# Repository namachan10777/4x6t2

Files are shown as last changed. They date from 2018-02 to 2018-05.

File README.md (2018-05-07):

# 4x6t2


4x6t2

A splited keyboard.
# License
MIT License 
Copyright (c) 2018 Nakano Masaki
## Exception
 * ./pcb/lib/4x6t2.pretty/MX_ALPS_KH_u1.00.kicad_mod
 * ./pcb/lib/4x6t2.pretty/D_SOD-123.kicad_mod
 * ./pcb/lib/4x6t2.pretty/LED_D3.0mm.kicad_mod
 * ./pcb/lib/4x6t2.pretty/R_Axial.kicad_mod
 * ./pcb/lib/4x6t2.pretty/SW_Tactile_SPST_Angled.kicad_mod
These footprint's original author is KiCAD.
These are distributed under CC-BY-SA 4.0.

# Third party
## helix
### point of use
 * Key footprint (./pcb/lib/4x6t2.pretty/MX_ALPS_KH_u1.00.kicad_mod) (modified)
 * Audio Jack footprint (./pcb/lib/4x6t2.pretty/MJ-4PP-9_rev2.kicad_mod)
### LICENSE
>Copyright (c) 2018 MakotoKurauchi
>
>Permission is hereby granted, free of charge, to any person obtaining a copy
>of this software and associated documentation files (the "Software"), to deal
>in the Software without restriction, including without limitation the rights
>to use, copy, modify, merge, publish, distribute, sublicense, and/or sell
>copies of the Software, and to permit persons to whom the Software is
>furnished to do so, subject to the following conditions:
>
>The above copyright notice and this permission notice shall be included in all
>copies or substantial portions of the Software.
>
>THE SOFTWARE IS PROVIDED "AS IS", WITHOUT WARRANTY OF ANY KIND, EXPRESS OR
>IMPLIED, INCLUDING BUT NOT LIMITED TO THE WARRANTIES OF MERCHANTABILITY,
>FITNESS FOR A PARTICULAR PURPOSE AND NONINFRINGEMENT. IN NO EVENT SHALL THE
>AUTHORS OR COPYRIGHT HOLDERS BE LIABLE FOR ANY CLAIM, DAMAGES OR OTHER
>LIABILITY, WHETHER IN AN ACTION OF CONTRACT, TORT OR OTHERWISE, ARISING FROM,
>OUT OF OR IN CONNECTION WITH THE SOFTWARE OR THE USE OR OTHER DEALINGS IN THE
>SOFTWARE.

## KiCAD Library
### LICENSE
CC-BY-SA 4.0
Copyright (c) KiCAD

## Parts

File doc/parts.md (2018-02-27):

# Basic
## Electrical parts
| Name | Qty |
|---|-----|
| SBD | 52  |
| Key Switch | 52  |
| 10 kΩ Resister | 6 |
| RJ45 Socket | 2 |
| 24p IC socket | 2 |
| Arduino Pro Micro | 2 |
| SPST snap in angled tactile switch | 2 |
## 3d parts
| Name | Qty |
|---|-----|
| spacer.stl | 4 |
| large_spacer.stl | 4 |
| vmount.stl | 2 |
| low_spacer.stl | 4 |
## PCB
| Name | Qty |
|---|---|
| left | 1 |
| right | 1 |
| breakout (Optional) | 25 x 3 |
## Mechanical Parts
| Name | Qty |
|---|-----|
| M3 20 screw | 6 |
| M3 nut | 6 |
| M6 screw (Optional) | 4 |
| M6 nut (Optional) | 8 |
# LED
## Electrical parts
| Name | Qty |
|---|-----|
| LED | 6 |
| Resister for LED | 6 |
# Sidebutton
## Electrical parts
| Name | Qty |
|---|-----|
| SPST tactile switch  | 1 |
| JT8P-3.2T-B10K-1-16Y | 1 |
## 3d parts
| Name | Qty |
|---|-----|
| joystick_cover.stl | 1 |
## PCB
| Name | Qty |
|---|-----|
| sidebutton | 1 |
## Mechanical parts
| Name | Qty |
|---|-----|
| M3 20 screw | 2 |
| M3 nut | 2 |
# Others
 * solder
 * wire

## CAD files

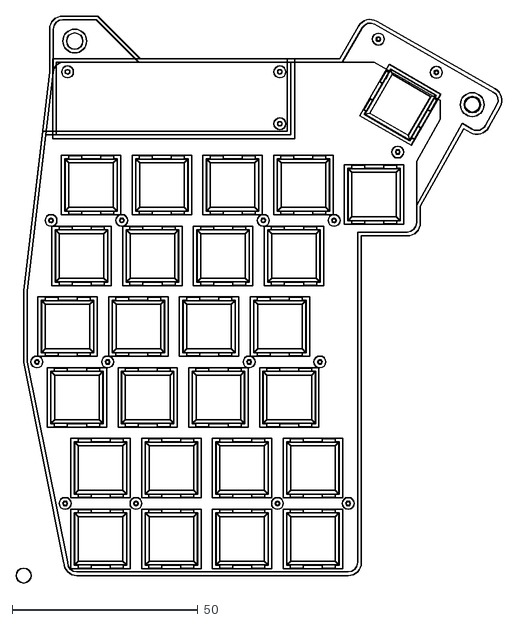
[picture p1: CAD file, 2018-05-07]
plate/plate.dxf
131.2 x 152.7

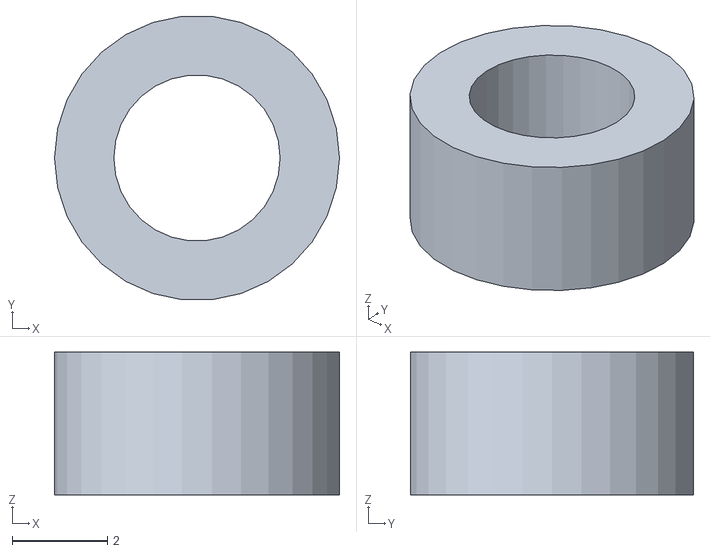
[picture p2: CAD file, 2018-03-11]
things/spacer.stl
6.00 x 5.97 x 3.00

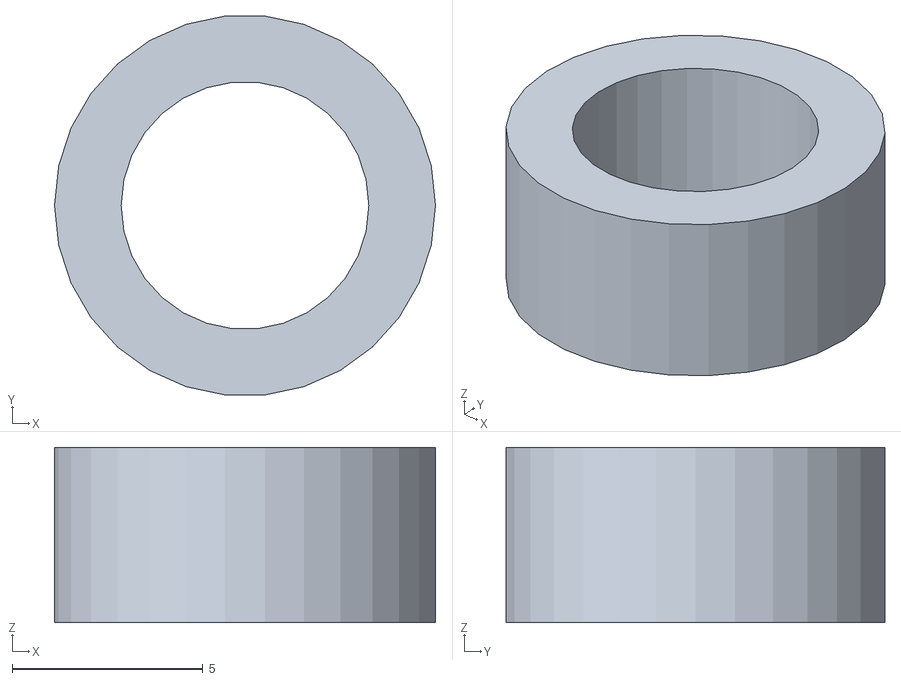
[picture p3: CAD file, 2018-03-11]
things/large_spacer.stl
10.0 x 9.95 x 4.60

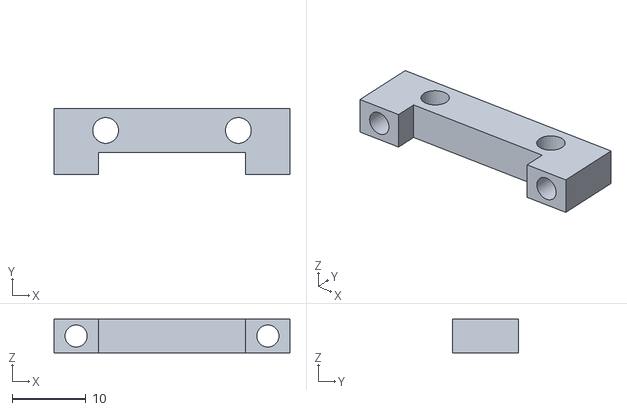
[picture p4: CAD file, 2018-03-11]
things/vmount.stl
32.0 x 9.00 x 4.60

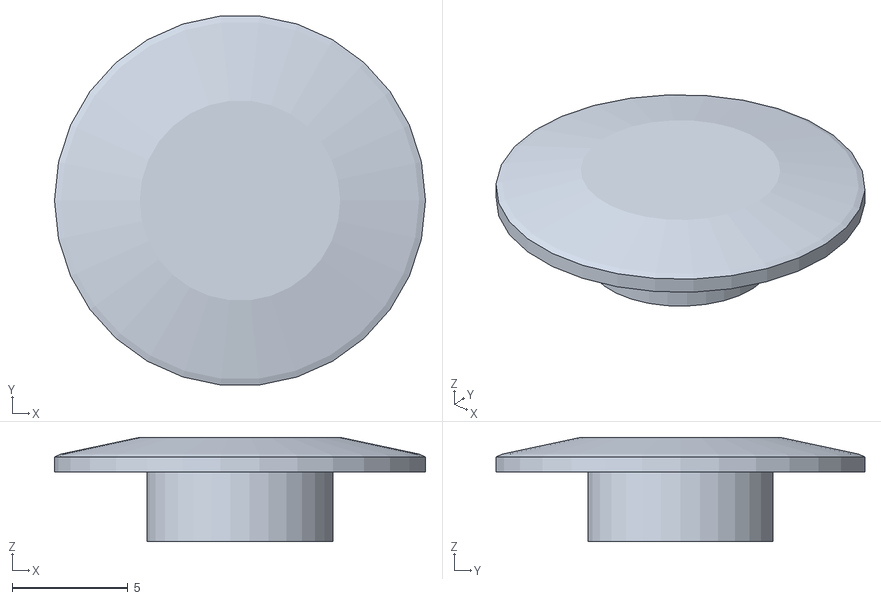
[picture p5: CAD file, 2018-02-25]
things/joystick_cover.stl
16.0 x 15.9 x 4.50

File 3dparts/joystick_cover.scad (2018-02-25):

difference() {
    intersection () {
        union() {
            cylinder(r=4, h=3, $fs=0.1);
            translate([0,0,3]) {
                cylinder(r=8, h=1.5, $fs=0.1);
            }
        }
        translate([0,0,-20]) {
            sphere(25);
        }
    }
    translate([-3.5/2,-4.5/2,0]) {
        cube([3.5,4.5,3]);
    }
}

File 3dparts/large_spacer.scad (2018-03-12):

difference(){
	height = 2.2+3+0.5-1.5;
    cylinder(r=5, h=height, center=true, $fs=0.1);
    cylinder(r=3.25, h=height, center=true, $fs=0.1);
}

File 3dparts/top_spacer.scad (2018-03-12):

difference() {
	height=1;
	hole_r=1.75;
	$fs=0.1;
	cylinder(h=height, r=3);
	cylinder(h=height, r=hole_r);
}

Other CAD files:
3dparts/under_spacer.scad
3dparts/vmount.scad

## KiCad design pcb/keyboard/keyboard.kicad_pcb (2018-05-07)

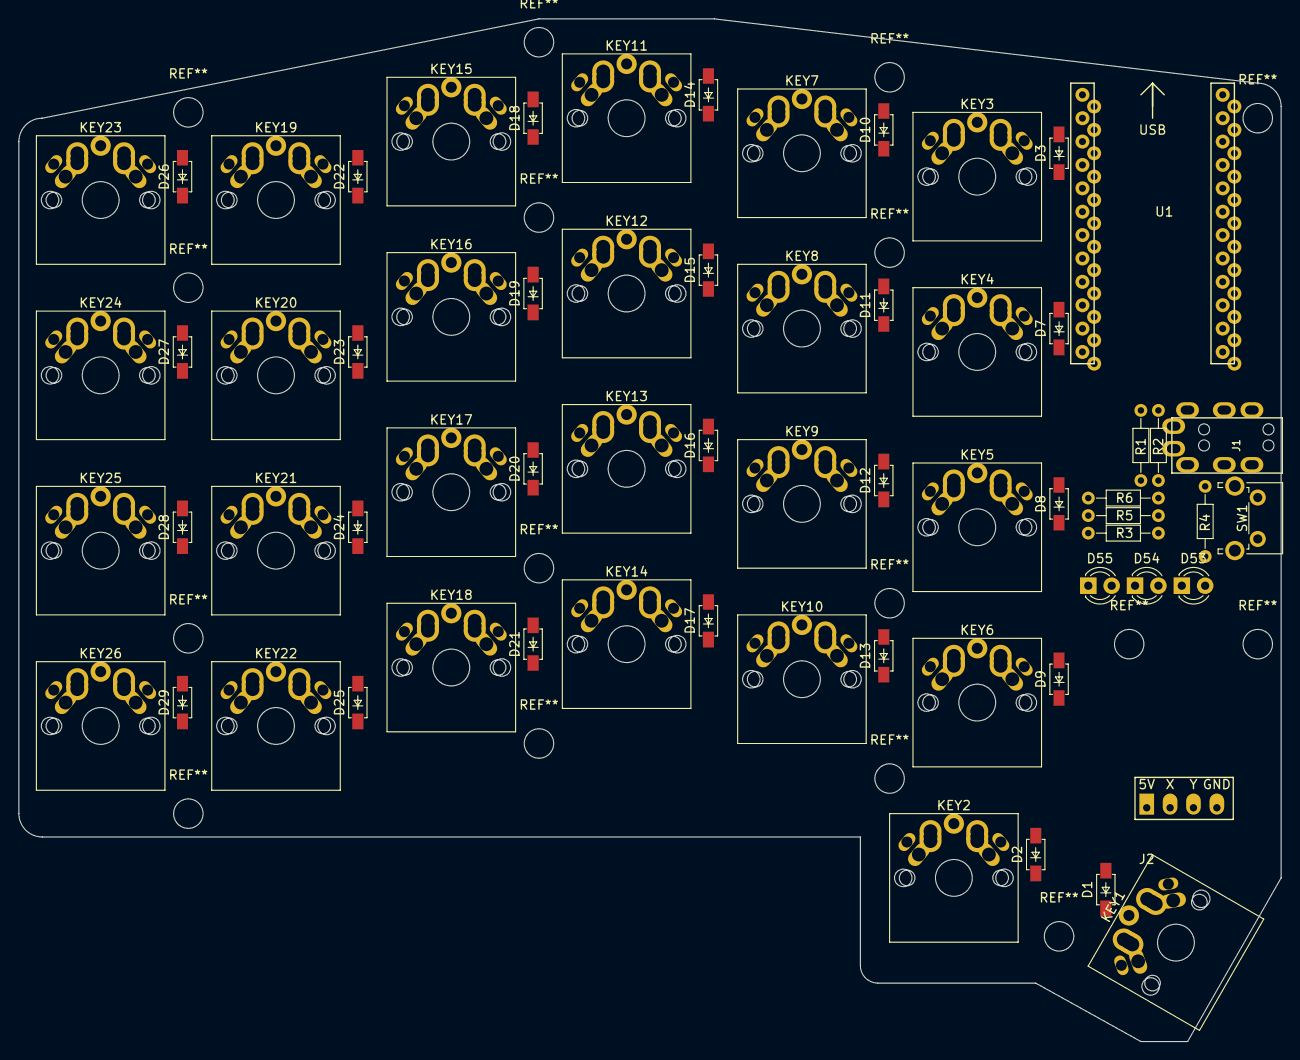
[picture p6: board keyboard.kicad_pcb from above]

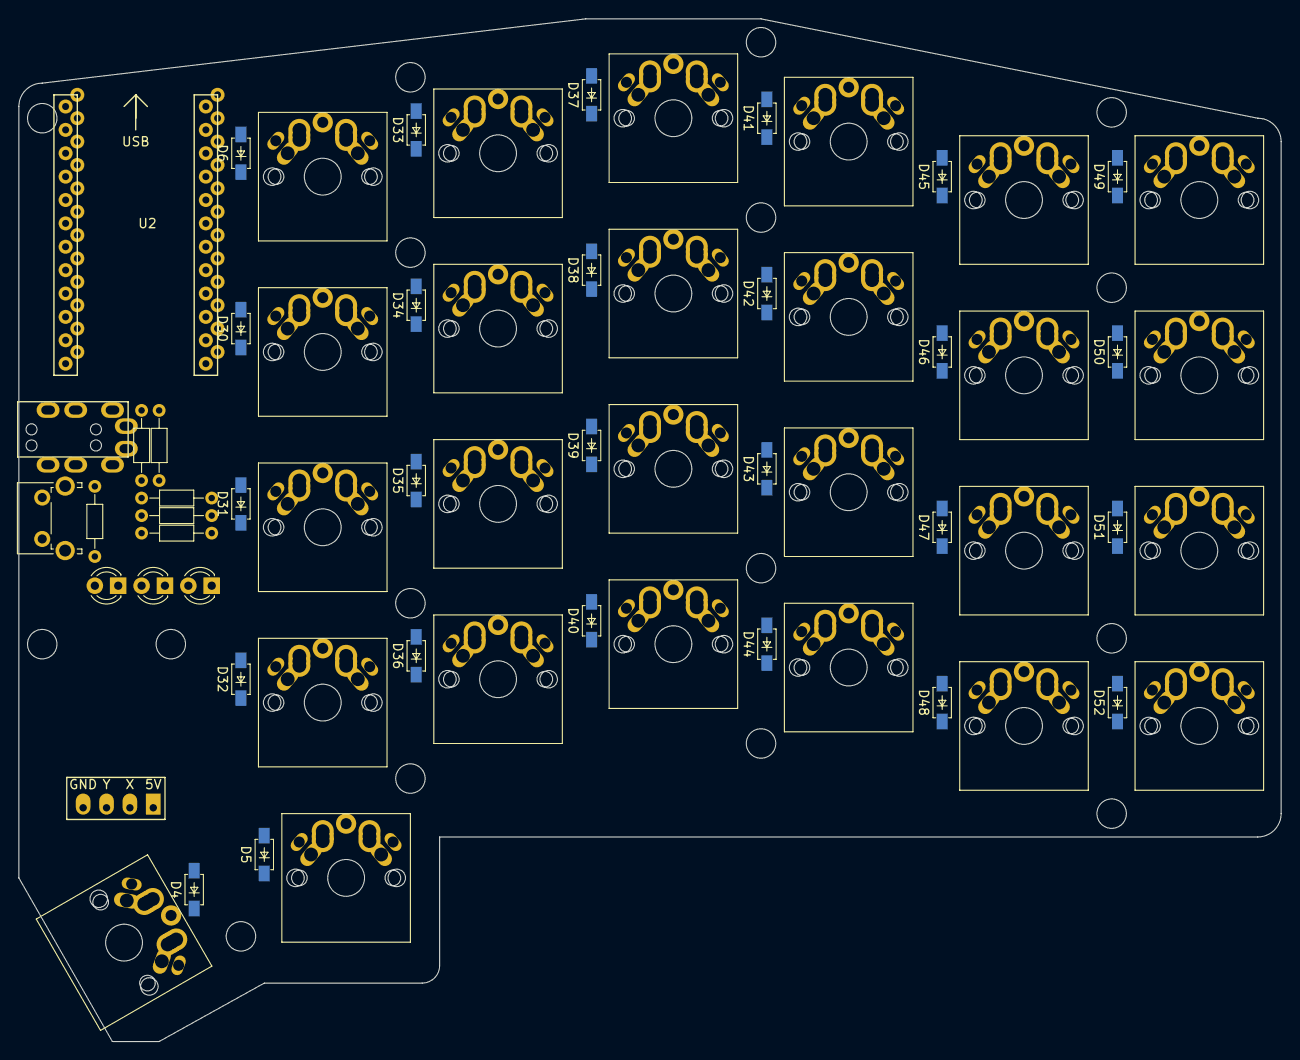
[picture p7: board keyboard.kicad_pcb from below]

Board: 2 copper layers, 137.2 x 111.1 mm, 92 parts (27 on the bottom side), 50 nets, no tracks yet.

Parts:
D1, D2, D3, D4, D5, D6, D7, D8, D9, D10, D11, D12, D13, D14, D15, D16, D17, D18, D19, D20, D21, D22, D23, D24, D25, D26, D27, D28, D29, D30, D31, D32, D33, D34, D35, D36, D37, D38, D39, D40, D41, D42, D43, D44, D45, D46, D47, D48, D49, D50, D51, D52: D; D_SOD-123
D53, D54, D55: LED; LED_D3.0mm
J1: Audio-Jack-4; MJ-4PP-9_rev2
J2: sidebutton; Wirepad_01x04
KEY1: KEY20; MX_ALPS_KH_u1.00
KEY2: KEY30; MX_ALPS_KH_u1.00
KEY3: KEY01; MX_ALPS_KH_u1.00
KEY4: KEY11; MX_ALPS_KH_u1.00
KEY5: KEY21; MX_ALPS_KH_u1.00
KEY6: KEY31; MX_ALPS_KH_u1.00
KEY7: KEY02; MX_ALPS_KH_u1.00
KEY8: KEY12; MX_ALPS_KH_u1.00
KEY9: KEY22; MX_ALPS_KH_u1.00
KEY10: KEY32; MX_ALPS_KH_u1.00
KEY11: KEY03; MX_ALPS_KH_u1.00
KEY12: KEY13; MX_ALPS_KH_u1.00
KEY13: KEY23; MX_ALPS_KH_u1.00
KEY14: KEY33; MX_ALPS_KH_u1.00
KEY15: KEY04; MX_ALPS_KH_u1.00
KEY16: KEY14; MX_ALPS_KH_u1.00
KEY17: KEY24; MX_ALPS_KH_u1.00
KEY18: KEY34; MX_ALPS_KH_u1.00
KEY19: KEY05; MX_ALPS_KH_u1.00
KEY20: KEY15; MX_ALPS_KH_u1.00
KEY21: KEY25; MX_ALPS_KH_u1.00
KEY22: KEY35; MX_ALPS_KH_u1.00
KEY23: KEY06; MX_ALPS_KH_u1.00
KEY24: KEY16; MX_ALPS_KH_u1.00
KEY25: KEY26; MX_ALPS_KH_u1.00
KEY26: KE36; MX_ALPS_KH_u1.00
R1, R2: 10kΩ; R_Axial
R3, R5, R6: 100Ω; R_Axial
R4: R; R_Axial
SW1: RESET_SW; SW_Tactile_SPST_Angled
U1, U2: Arduino_Pro_Micro

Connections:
+5V: J1.3, J2.1, R1.1, R2.1, R3.1, R4.1, R5.1, R6.1, U1.21, U2.21
/COL0: D1.2, D2.2, D4.2, D5.2, U1.17, U2.17
/COL1: D3.2, D6.2, D7.2, D8.2, D9.2, D30.2, D31.2, D32.2, U1.16, U2.16
/COL2: D10.2, D11.2, D12.2, D13.2, D33.2, D34.2, D35.2, D36.2, U1.15, U2.15
/COL3: D14.2, D15.2, D16.2, D17.2, D37.2, D38.2, D39.2, D40.2, U1.14, U2.14
/COL4: D18.2, D19.2, D20.2, D21.2, D41.2, D42.2, D43.2, D44.2, U1.13, U2.13
/COL5: D22.2, D23.2, D24.2, D25.2, D45.2, D46.2, D47.2, D48.2, U1.11, U2.11
/COL6: D26.2, D27.2, D28.2, D29.2, D49.2, D50.2, D51.2, D52.2, U1.12, U2.12
/LED1: D53.1, U1.20, U2.20
/LED2: D54.1, U1.19, U2.19
/LED3: D55.1, U1.18, U2.18
/ROW0: KEY3.1, KEY7.1, KEY11.1, KEY15.1, KEY19.1, KEY23.1, U1.1, U2.1
/ROW1: KEY4.1, KEY8.1, KEY12.1, KEY16.1, KEY20.1, KEY24.1, U1.2, U2.2
/ROW2: KEY1.1, KEY5.1, KEY9.1, KEY13.1, KEY17.1, KEY21.1, KEY25.1, U1.8, U2.8
/ROW4: KEY2.1, KEY6.1, KEY10.1, KEY14.1, KEY18.1, KEY22.1, KEY26.1, U1.10, U2.10
/RST: R4.2, SW1.1, U1.22, U2.22
/SCL: J1.1, R1.2, U1.6, U2.6
/SDA: J1.2, R2.2, U1.5, U2.5
/X: J2.2, U1.9, U2.9
/Y: J2.3, U1.7, U2.7
GND: J1.4, J2.4, SW1.2, U1.3, U1.4, U1.23, U2.3, U2.4, U2.23
unnamed: D1.1, D4.1, KEY1.2
unnamed: D2.1, D5.1, KEY2.2
unnamed: D3.1, D6.1, KEY3.2
unnamed: D10.1, D33.1, KEY7.2
unnamed: D11.1, D34.1, KEY8.2
unnamed: D12.1, D35.1, KEY9.2
unnamed: D13.1, D36.1, KEY10.2
unnamed: D14.1, D37.1, KEY11.2
unnamed: D15.1, D38.1, KEY12.2
unnamed: D16.1, D39.1, KEY13.2
unnamed: D17.1, D40.1, KEY14.2
unnamed: D18.1, D41.1, KEY15.2
unnamed: D19.1, D42.1, KEY16.2
unnamed: D20.1, D43.1, KEY17.2
unnamed: D21.1, D44.1, KEY18.2
unnamed: D22.1, D45.1, KEY19.2
unnamed: D23.1, D46.1, KEY20.2
unnamed: D24.1, D47.1, KEY21.2
unnamed: D25.1, D48.1, KEY22.2
unnamed: D26.1, D49.1, KEY23.2
unnamed: D27.1, D50.1, KEY24.2
unnamed: D28.1, D51.1, KEY25.2
unnamed: D29.1, D52.1, KEY26.2
unnamed: D7.1, D30.1, KEY4.2
unnamed: D8.1, D31.1, KEY5.2
unnamed: D9.1, D32.1, KEY6.2
unnamed: D53.2, R3.2
unnamed: D54.2, R5.2
unnamed: D55.2, R6.2

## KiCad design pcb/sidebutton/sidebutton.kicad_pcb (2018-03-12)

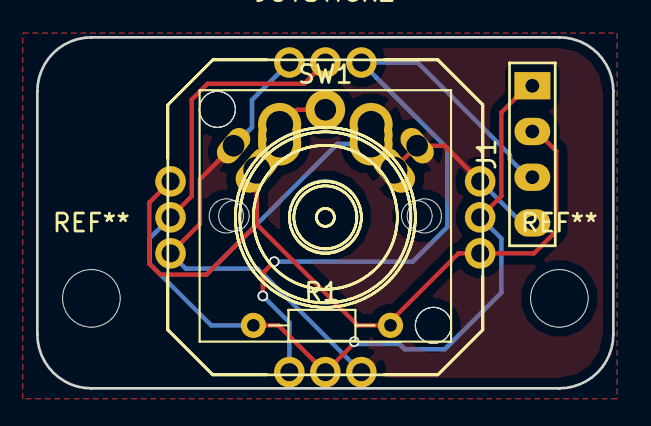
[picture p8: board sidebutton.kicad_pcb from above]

Board: 2 copper layers, 32.0 x 19.5 mm, 5 parts (0 on the bottom side), 4 nets.

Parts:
J1: Conn_01x04; Wirepad_01x04
JOYSTICK1, JOYSTICK2: JT8P-3.2T-B10K-1-16Y
R1: R; R_Axial_DIN0204_L3.6mm_D1.6mm_P7.62mm_Horizontal
SW1: SW_DIP_x01; MX_ALPS_KH_u1.00

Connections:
+5V: J1.1, JOYSTICK1.2, JOYSTICK1.5, JOYSTICK2.2, JOYSTICK2.5, R1.1
/out1: J1.2, JOYSTICK1.4, JOYSTICK2.4, R1.2, SW1.2
/out2: J1.3, JOYSTICK1.1, JOYSTICK2.1
GND: J1.4, JOYSTICK1.3, JOYSTICK1.6, JOYSTICK2.3, JOYSTICK2.6, SW1.1

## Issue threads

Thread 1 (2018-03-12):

KiCAdライブラリのライセンス

namachan10777, 2018-03-12:
CC-BY-SA 4.0かGPL v2.どちらにせよ違反なので修正

Closed 2018-03-14.

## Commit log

2018-02-18 add RJ45-8pin KiCADのRJ45はフットプリントと対応してない(なんで)ので
2018-02-18 lib: add Arduino Pro Micro
2018-02-19 left: add schematic
    [left.sch]
2018-02-19 add 30 degree rotated key footprint
2018-02-19 add joystic to schematic
    [left.sch]
2018-02-19 add left pcb arrangement
    [left.kicad_pcb]
2018-02-20 add joystick pcb
    [joystick.kicad_pcb, joystick.sch]
2018-02-20 improve pcb design
    [joystick.kicad_pcb, joystick.sch, left.kicad_pcb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]
2018-02-21 improve key arrangement
    [left.kicad_pcb, left.sch, sidebutton.kicad_pcb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]
2018-02-22 add plate artwork
    [plate.dxf]
2018-02-23 fix sidebutton めっちゃブリッジしそうで怖い
    [sidebutton.kicad_pcb, sidebutton.sch]
2018-02-23 small pcb キーの配線は空中配線で
    [left.kicad_pcb, left.sch]
2018-02-23 left: place all parts
    [left.kicad_pcb]
2018-02-23 improve basic design
    [left.kicad_pcb, plate.dxf]
2018-02-24 sidebutton pcb became reversible
    [sidebutton.kicad_pcb, sidebutton.sch]
2018-02-24 fix sidebutton pcb 穴間の修正
    [sidebutton.kicad_pcb]
2018-02-24 add spacer source code
    [low_spacer.scad, spacer.scad, vmount.scad]
2018-02-24 resize pcb shorten pcb length a bit.
    [left.kicad_pcb]
2018-02-24 avoid vmount and pcb conflict
    [plate.dxf]
2018-02-24 wiring left
    [left.kicad_pcb]
2018-02-24 fix LED arrangement LED conflicted with Pro Micro
    [left.kicad_pcb]
2018-02-24 add right pcb
    [right.kicad_pcb, right.sch]
2018-02-25 fix pcb size
    [left.kicad_pcb, plate.dxf, right.kicad_pcb]
2018-02-25 fix hole position of vmount.scad
    [vmount.scad]
2018-02-25 add large_spacer.scad
    [large_spacer.scad]
2018-02-25 fix hole position
    [plate.dxf]
2018-02-25 add STL file
    [large_spacer.stl, low_spacer.stl, spacer.stl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]
2018-02-25 add pcb cover
    [pro_micro_cover.dxf]
2018-02-25 add joystick cover
    [joystick_cover.scad, joystick_cover.stl]
2018-02-25 rename spacer -> 3dparts
    [joystick_cover.scad, large_spacer.scad, low_spacer.scad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]
2018-02-26 ignore gerber data
2018-02-27 improve parts arrangement
    [left.kicad_pcb, left.sch, right.kicad_pcb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]
2018-02-27 improve pcb size
    [left.kicad_pcb, right.kicad_pcb]
2018-02-27 fix plate
    [plate.dxf, pro_micro_cover.dxf]
2018-02-27 connect pad
    [left.kicad_pcb, right.kicad_pcb]
2018-02-27 add Cherry MX breakout
    [breakout.kicad_pcb, breakout.sch]
2018-02-27 reduction breakout
    [breakout.kicad_pcb]
2018-02-27 add panelized breakout
    [panelized.kicad_pcb]
2018-03-04 left: large pcb
    [left.kicad_pcb, left.sch]
2018-03-04 add hybrid keyboard footprint
2018-03-05 fix pcb outline
    [left.kicad_pcb]
2018-03-05 add reversible keyboard pcb
    [breakout.kicad_pcb, breakout.sch, keyboard.kicad_pcb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]
2018-03-05 minimize vmout
    [vmount.scad, vmount.stl]
2018-03-05 fix plate design
    [plate.dxf]
2018-03-05 fix sidebutton pcb design
    [sidebutton.kicad_pcb]
2018-03-05 connect 2 vmount
    [vmount.scad, vmount.stl]
2018-03-07 add Kailh low profile adapted footprint
2018-03-07 place new key footprints
    [keyboard.kicad_pcb, keyboard.sch]
2018-03-07 tweak little finger key position
    [keyboard.kicad_pcb]
2018-03-07 audio jack footprint: fix pin number
2018-03-07 RJ45 -> Audio Jack 4pin
    [keyboard.kicad_pcb, keyboard.sch]
2018-03-07 sidebutton use KH key
    [sidebutton.kicad_pcb, sidebutton.sch]
2018-03-07 imporve design
    * 小指の担当部の薬指との差をゆるく
    * PCBの切り詰め(強度はプレートで担保)
    [keyboard.kicad_pcb, plate.dxf]
2018-03-07 fix vmount.scad
    [vmount.scad, vmount.stl]
2018-03-07 abolish trancated 値段変わらなくない?
    [keyboard.kicad_pcb]
2018-03-09 fix top plate cut for pro micro and audio jack
    [plate.dxf]
2018-03-10 keyboard pcb: add R
    [keyboard.kicad_pcb]
2018-03-10 sidebutton pcb: add R
    [sidebutton.kicad_pcb]
2018-03-10 packing script: fix missing drill data bug
2018-03-10 release script: fix elecrow drill data is gerber. But fusionpcb request postscript drill data.
2018-03-11 change pro micro footprint
2018-03-11 fix pro micro upside donw
    [keyboard.kicad_pcb, keyboard.sch]
2018-03-11 sidebutton conn: XH -> Wirepad
    [keyboard.kicad_pcb, keyboard.sch]
2018-03-11 fix vmount.scad height horizontal screw: M3 -> M2.5
    [vmount.scad, vmount.stl]
2018-03-11 fix spacers
    [large_spacer.scad, large_spacer.stl, low_spacer.scad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]
2018-03-11 sidebutton: add GND solid
    [sidebutton.kicad_pcb]
2018-03-12 switching diode: THT -> SMD
    [keyboard.kicad_pcb, keyboard.sch]
2018-03-12 remove bottom plate lightening holes
    [plate.dxf]
2018-03-12 missing commit
    [plate.dxf]
2018-03-12 change space between top plate and under plate
    4.6 -> 4.2 mm
    [large_spacer.scad, spacer.scad, top_spacer.scad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]
2018-03-12 confirm plate thickness
2018-03-12 fix sidebutton mounting position
    [sidebutton.kicad_pcb]
2018-03-14 i2c: pull down -> pull up
    [keyboard.kicad_pcb, keyboard.sch]
2018-03-14 add missing R
    [keyboard.kicad_pcb]
2018-03-14 fix spacer height
    [under_spacer.scad, vmount.scad]
2018-03-15 add LED
    [keyboard.kicad_pcb, keyboard.sch]
2018-03-16 emlarge via drill size 0.2032 -> 0.3
    [keyboard.kicad_pcb]
2018-03-22 improve footprints
2018-03-24 improve promicro footprint
2018-03-24 improve silk and holes
    [keyboard.kicad_pcb, keyboard.sch]
2018-04-17 fix schematic
    [keyboard.kicad_pcb, keyboard.sch, plate.dxf]
